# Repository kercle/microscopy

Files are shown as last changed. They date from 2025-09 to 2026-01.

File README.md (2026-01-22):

# Microscope automation project

This is a small passion project of mine in which I implement a few automations to my Bresser Researcher Trino 40-1000x. A few design-goals are:

- Minimally intrusive in the sense that the changes to the microscope should be revertible as much as possible.
- The microscope should still be fully usable in the original (analogue) way.

## Gallery

A few composite images obtained by focus stacking:

| Daphnia | Spider mite | Unknown mite |
|---|---|---|
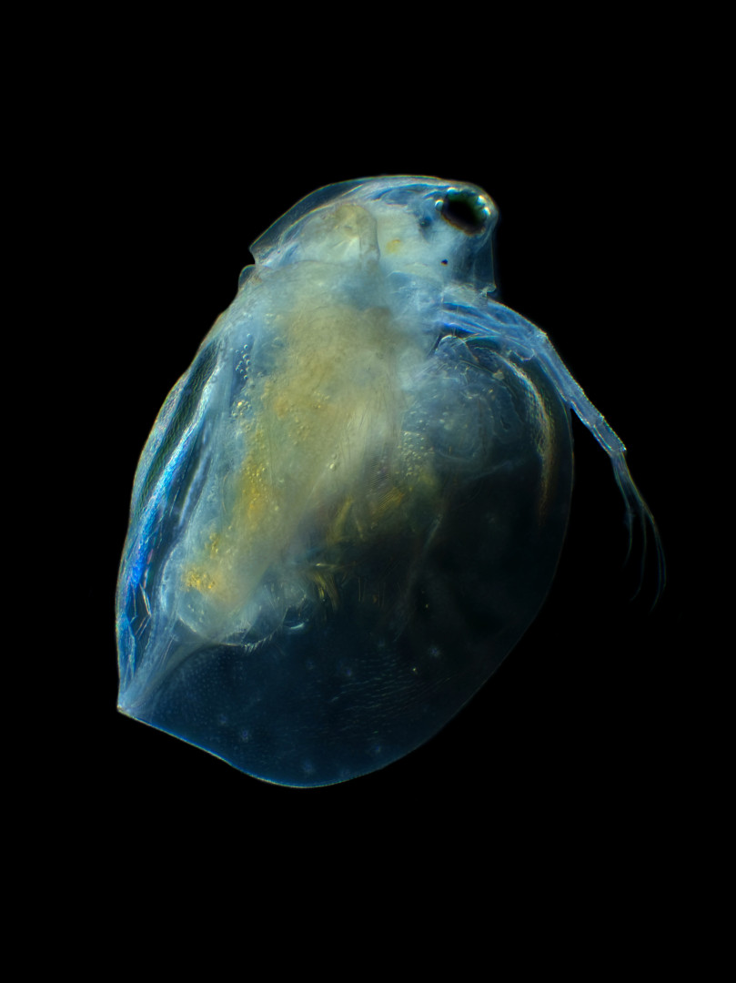
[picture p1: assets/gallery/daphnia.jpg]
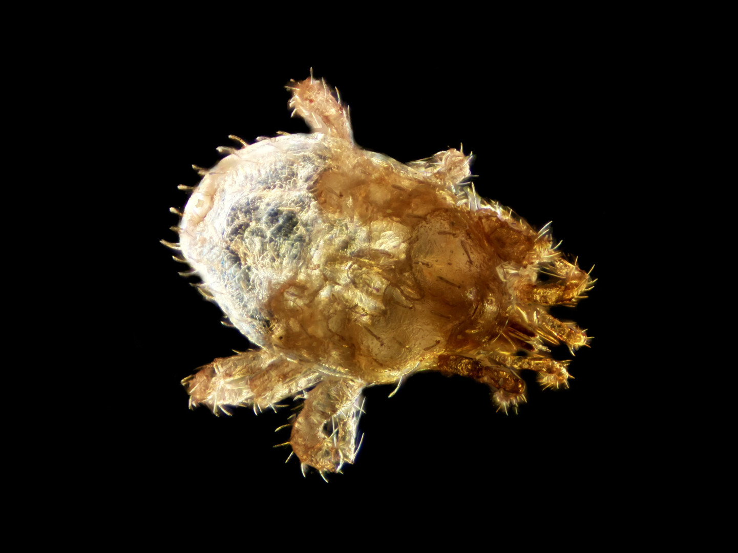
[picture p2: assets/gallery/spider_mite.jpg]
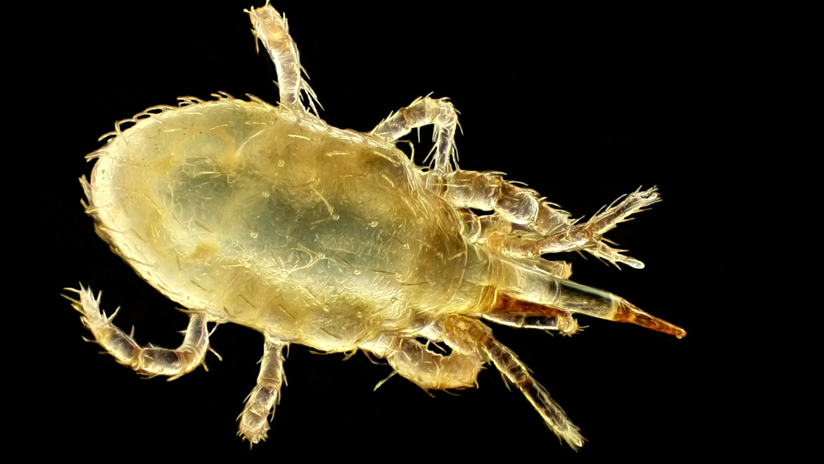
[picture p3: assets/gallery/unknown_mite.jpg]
|  |  |  |
| *Notes:* The sample was treated with bleach in order to immobilize organisms. Brownian motion was prevented by stabilizing the sample in Xanthan gum. | *Notes:* The sample was frozen to immobilize the specimen. It was taken from one of my house plants. | *Notes:* The sample was collected from the soil in one of my house plants. It was immobilized by freezing. Possibly of the order Mesostigmata. |

## Hardware

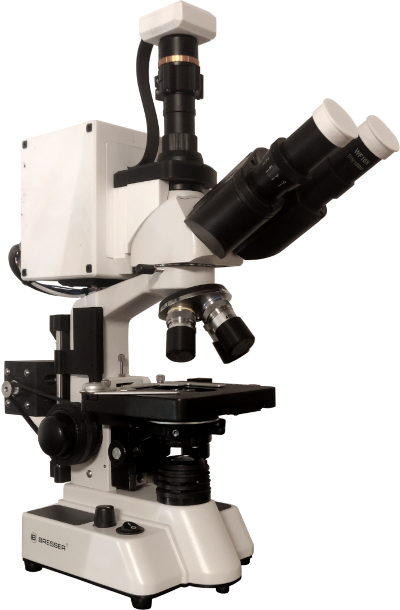
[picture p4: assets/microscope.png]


### Electronics

The control electronics is split between two controllers. The low-level control is handled by an ESP32 microcontroller, with the stepping motors being driven by TMC2208 stepper drivers.

The high-level control is handled by a Raspberry Pi 4, however the housing also allows for the installation of a Jetson Nano device instead of the Raspberry Pi.

The Raspberry Pi and ESP32 communicate over a serial connection (UART) using a custom protocol.

## Software

### User interface and backend

The user interface is a web application served by the Raspberry Pi. The frontend is built using Svelte, Tailwind CSS and DaisyUI. The backend is a Rust application using the Axum framework.

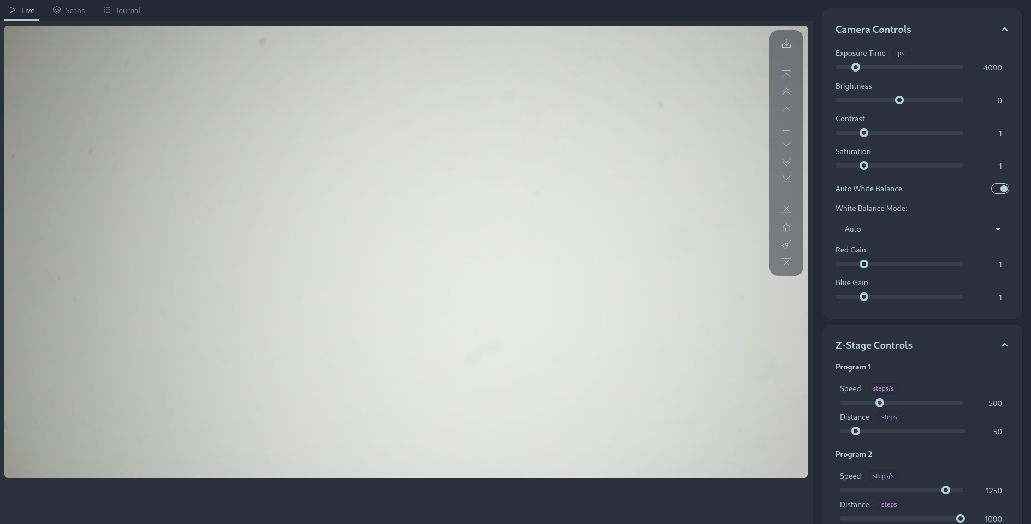
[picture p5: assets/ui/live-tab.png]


### Firmware

The ESP32 firmware is written in Rust using the `esp-idf` framework and embassy.

## Roadmap / Ideas for future work

- [x] Motorized z-axis with endstops for focusing
- [x] Web interface for controlling the microscope
- [x] Live view from camera with controls for exposure, gain, white balance, etc.
- [x] Z-stack acquisition
- [ ] Build custom focus knob which interacts with the microcontroller to allow for manual focusing when not using the web interface.
- [ ] Motorized stage for x/y movement
- [ ] Build custom stage knobs which interact with the microcontroller to allow for manual x/y
- [ ] Objective turret slot detection
- [ ] Substage illumination control
- [ ] Incident illumination

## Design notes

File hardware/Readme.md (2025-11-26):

# Hardware specifications

## Mechanical components

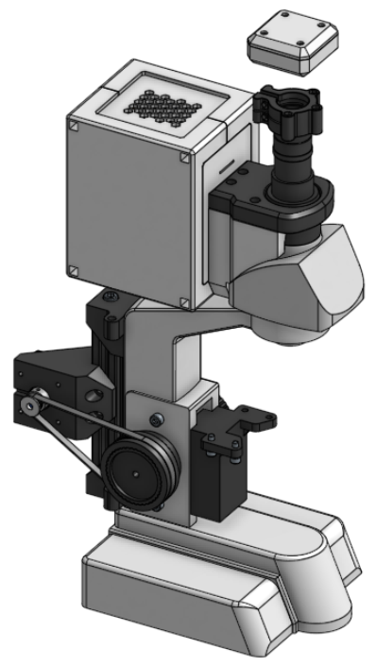
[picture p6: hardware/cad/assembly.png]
Mechanical Components


Most of the parts are 3D printed, however a few are laser cut from acrylic sheet.
Eventually, I plan to either make all of them 3D-printable and if acrylic sheets
are needed, they should be designed such that they can be cut out by hand as well
(e.g. the side panels for the electronics enclosure).

### BOM

| Part | Description | Quantity |
|---|---|---|
| | | |
| | | |

## Driver board

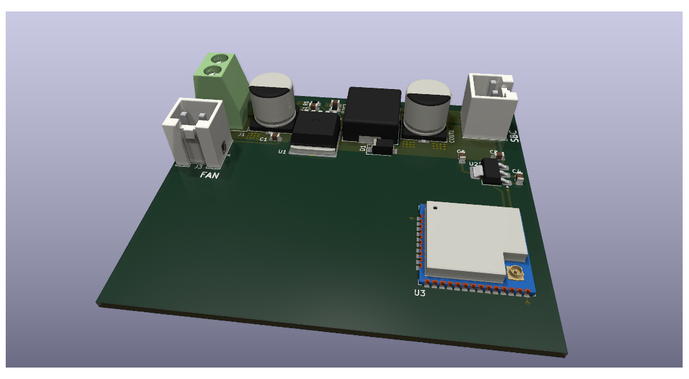
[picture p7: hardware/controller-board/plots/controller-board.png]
Driver Board


The driver board is not yet finished and so far only the power supply part is
designed, however it still needs some review, since I'm not an expert in PCB
design. The micro-controller is an ESP32-WROOM module, since the firmware is
written in Rust and the Espressif toolchain for Rust is quite mature.

### BOM

| Part | Description | Quantity |
|---|---|---|
| | | |
| | | |

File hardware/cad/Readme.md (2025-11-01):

# CAD Models

Most CAD models for this project are made in Onshape, however at some point, I would like to migrate to OpenSCAD for better version control and project portability.

The Onshape project can be found [here](https://cad.onshape.com/documents/6a7b17c2abfc874842839c22/w/c10742419820c2ced297c4e5/e/144f9c4804ce72fdaecba7c3).



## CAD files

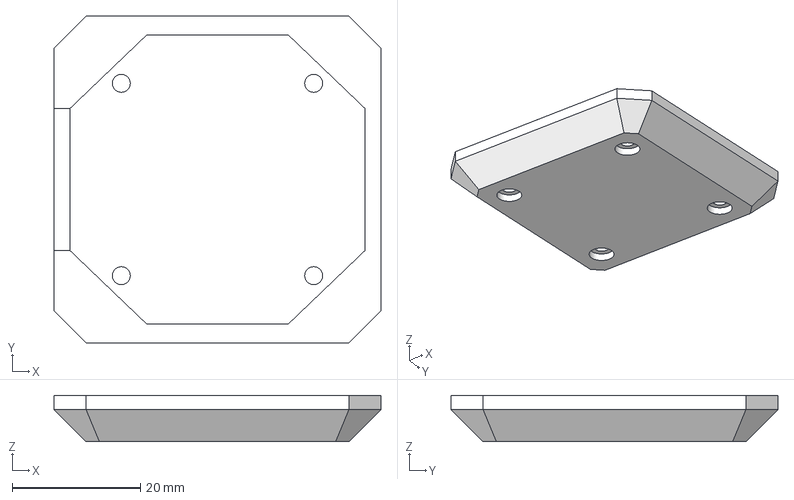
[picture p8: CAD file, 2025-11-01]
hardware/cad/camera/Camera Case - Cover.step
51.0 x 51.0 x 7.20 mm

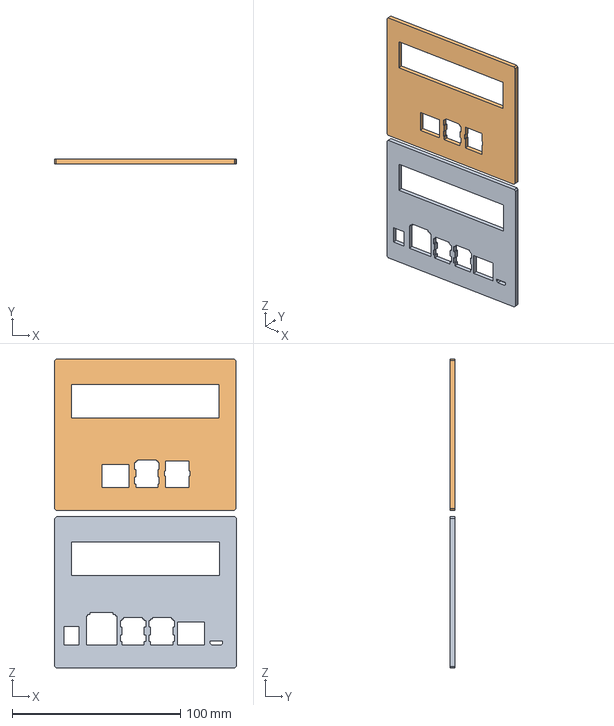
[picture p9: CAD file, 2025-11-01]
hardware/cad/housing/Port Plates.step
108.2 x 3.00 x 183.4 mm

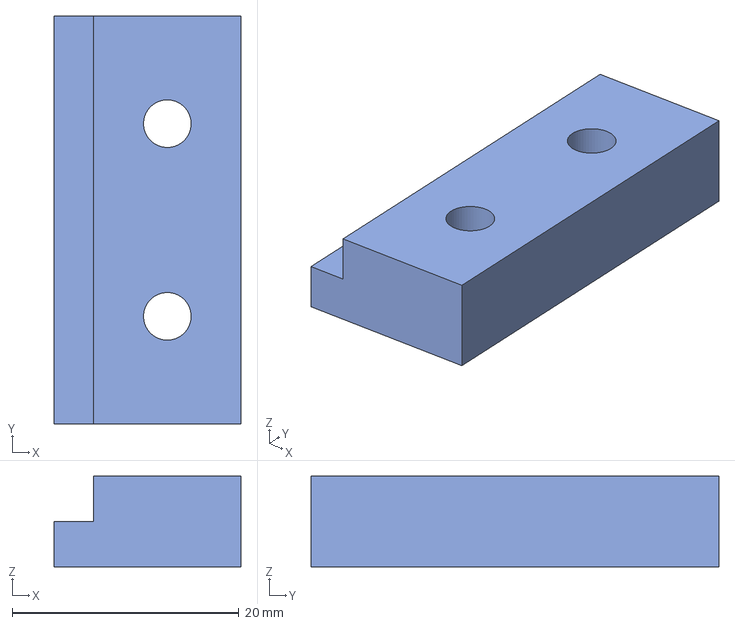
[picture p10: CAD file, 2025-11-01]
hardware/cad/mounting/Head Attachment - Retainer.step
16.5 x 36.0 x 8.00 mm

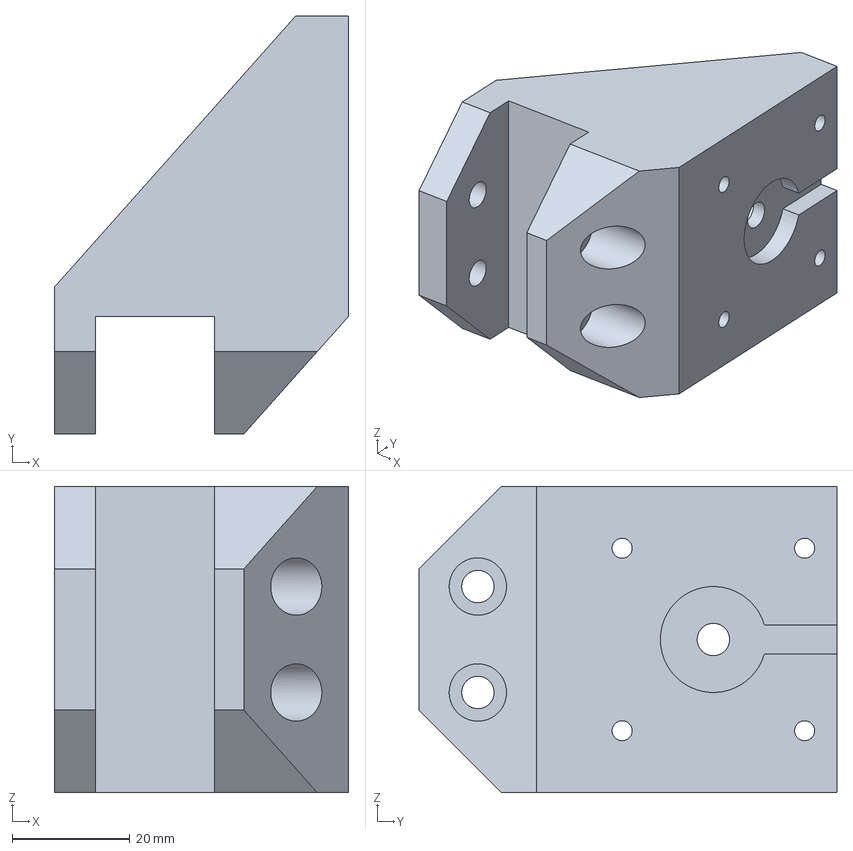
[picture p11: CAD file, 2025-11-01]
hardware/cad/z-stage/drive/Stepper - Mounting Bracket.step
50.0 x 71.0 x 52.0 mm

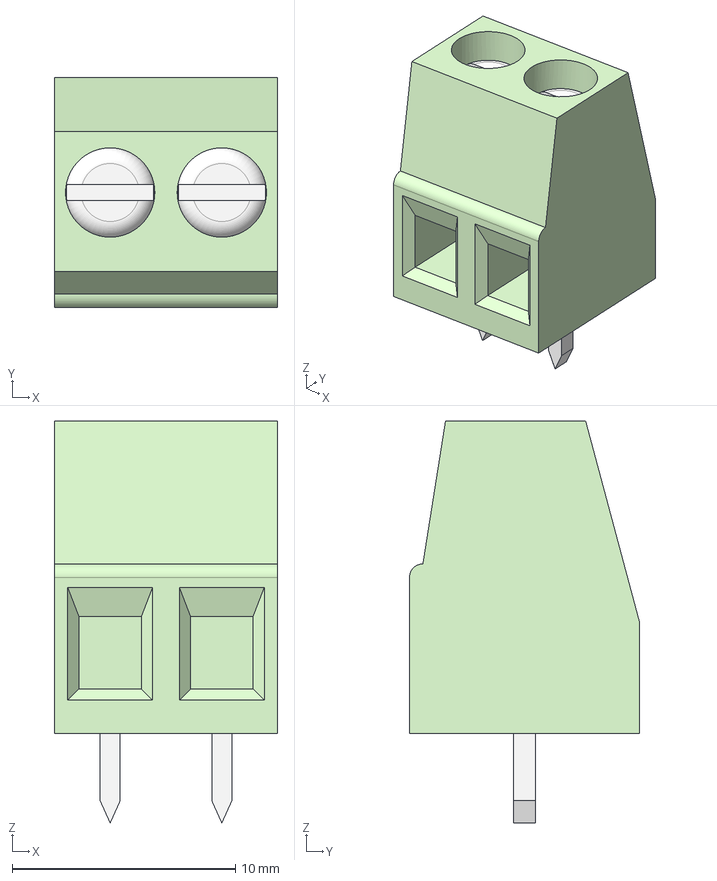
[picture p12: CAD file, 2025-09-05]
hardware/controller-board/parts/models/WJ128-5.0-2P.step
10.0 x 10.3 x 18.0 mm

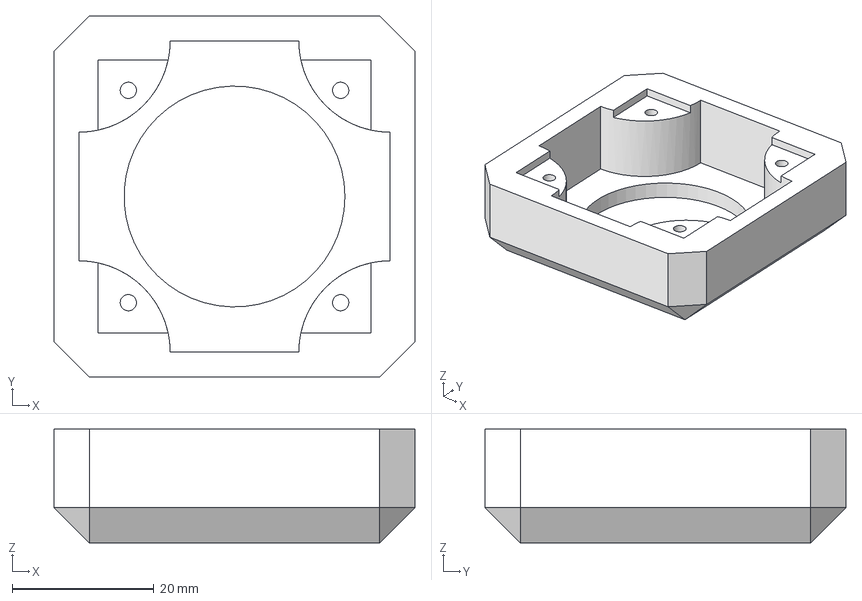
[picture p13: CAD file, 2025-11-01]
hardware/cad/camera/Camera Case - Base.step
51.0 x 51.0 x 16.1 mm

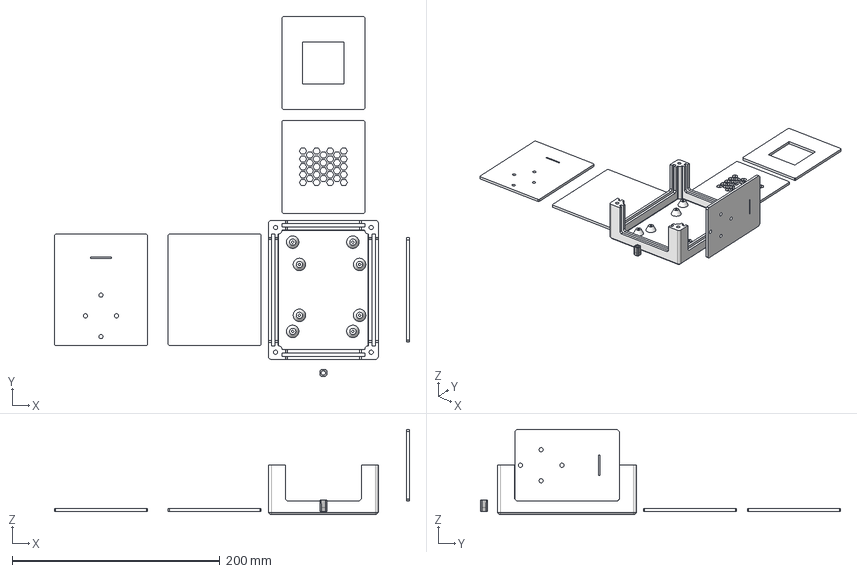
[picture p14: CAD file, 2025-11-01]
hardware/cad/housing/Electronics Housing Shell.step
342.1 x 346.9 x 82.2 mm

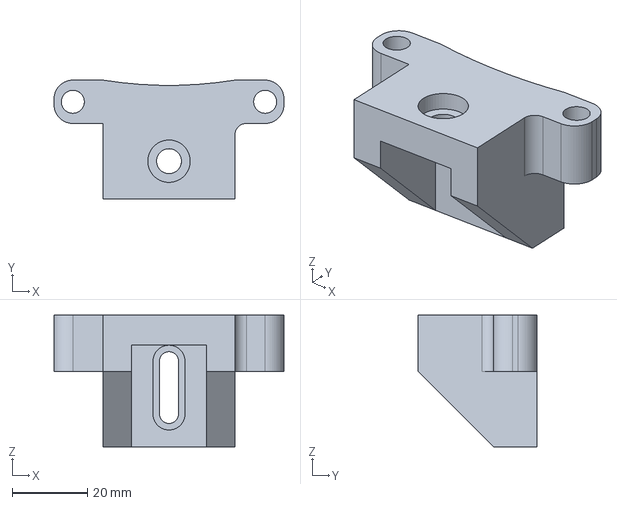
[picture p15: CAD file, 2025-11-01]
hardware/cad/mounting/Back Rail - Body Adapter.step
61.0 x 31.5 x 35.0 mm

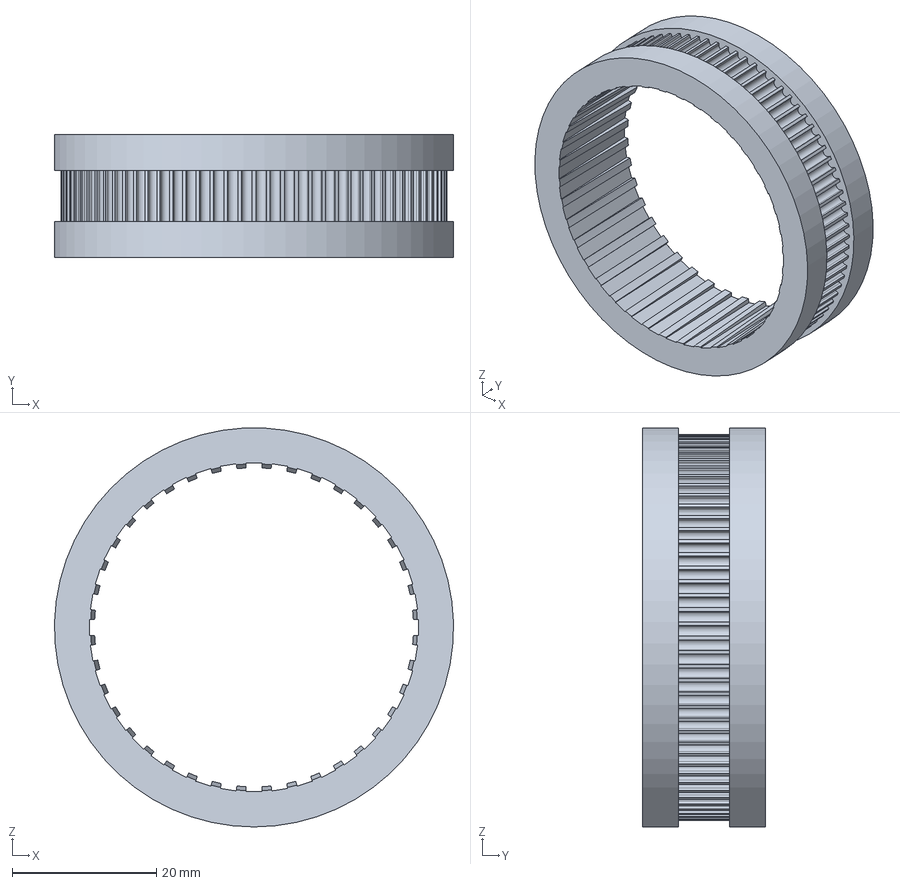
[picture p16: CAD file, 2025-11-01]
hardware/cad/z-stage/drive/Belt Focus Drive - Belt Focus Drive.step
55.3 x 17.0 x 55.3 mm

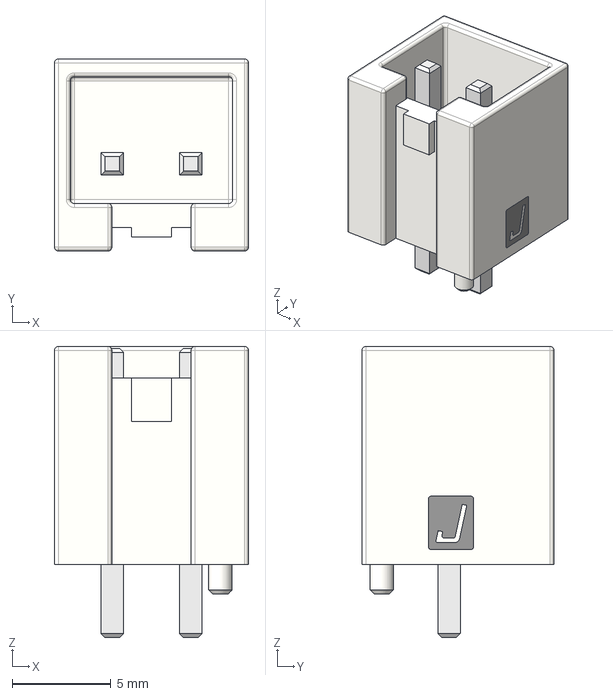
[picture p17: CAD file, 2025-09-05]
hardware/controller-board/parts/models/B2P-VH-FB-B_LF__SN_.stp
9.80 x 9.70 x 14.7 mm

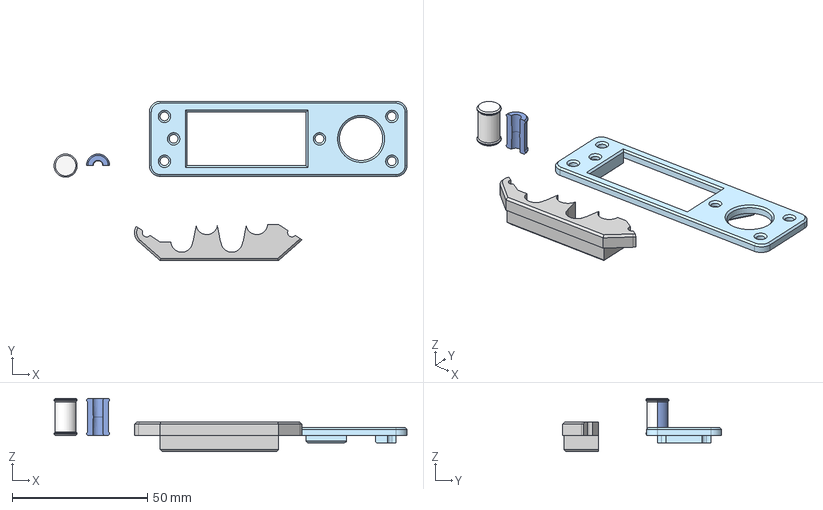
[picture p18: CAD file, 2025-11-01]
hardware/cad/housing/Custom Ports Panel.step
130.7 x 59.0 x 19.8 mm

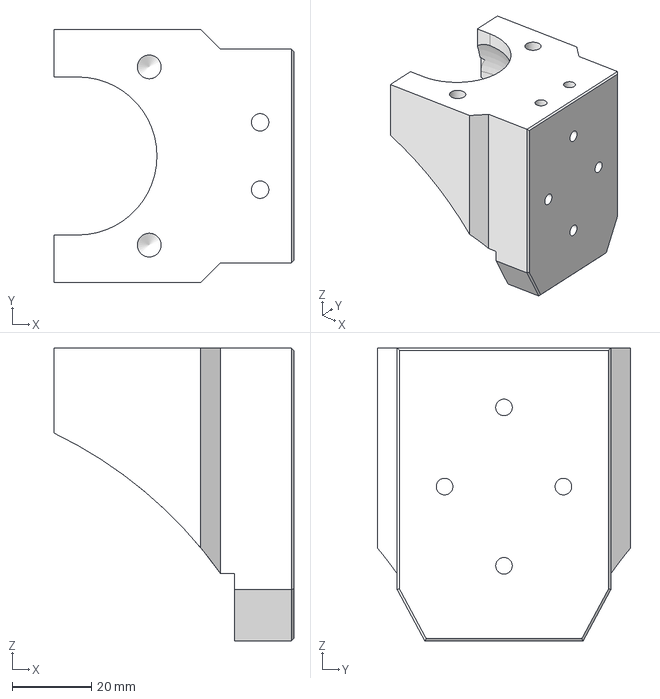
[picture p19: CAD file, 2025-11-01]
hardware/cad/mounting/Head Attachment - Head Attachment.step
60.5 x 64.0 x 74.0 mm

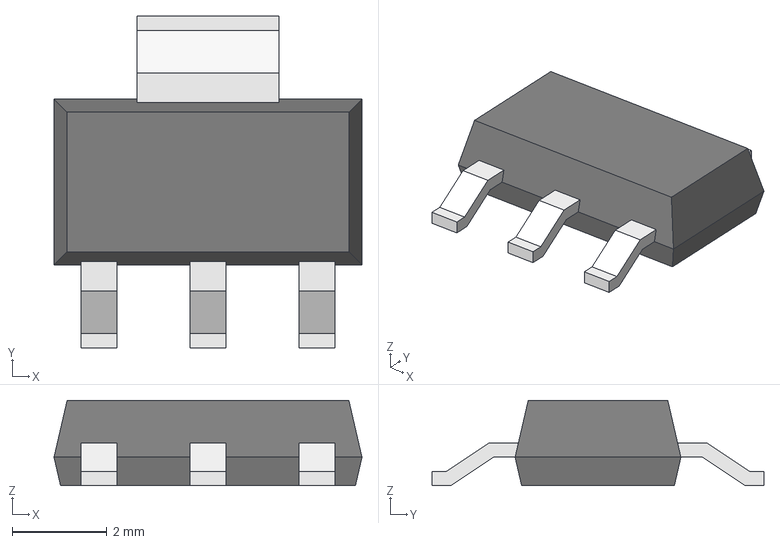
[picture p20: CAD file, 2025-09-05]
hardware/controller-board/parts/models/AMS1117.step
6.50 x 7.00 x 1.80 mm

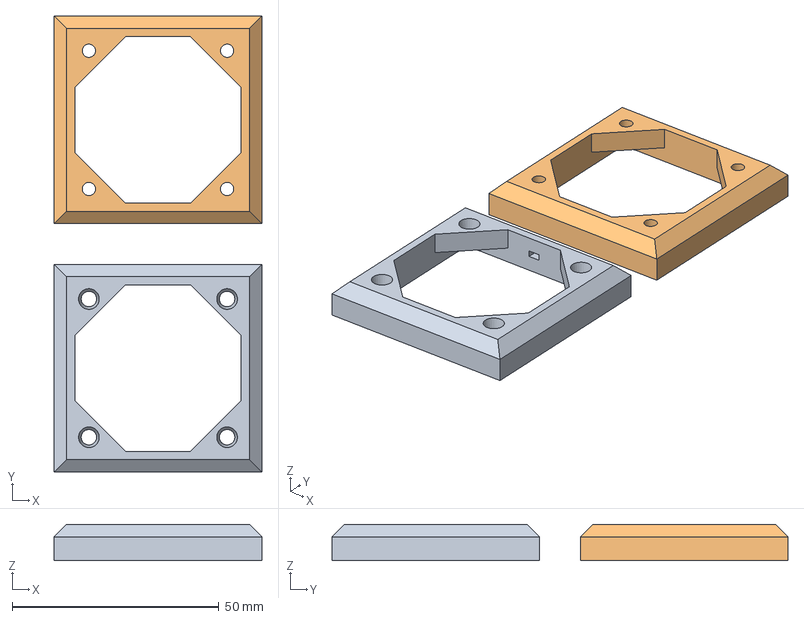
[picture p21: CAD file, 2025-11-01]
hardware/cad/housing/Fan Bracket.step
50.2 x 110.2 x 8.75 mm

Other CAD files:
hardware/cad/mounting/Reducer Lense - Clamp.step
hardware/controller-board/parts/models/YSPI1365.step
hardware/cad/mounting/Head Attachment - Bracket Top.step

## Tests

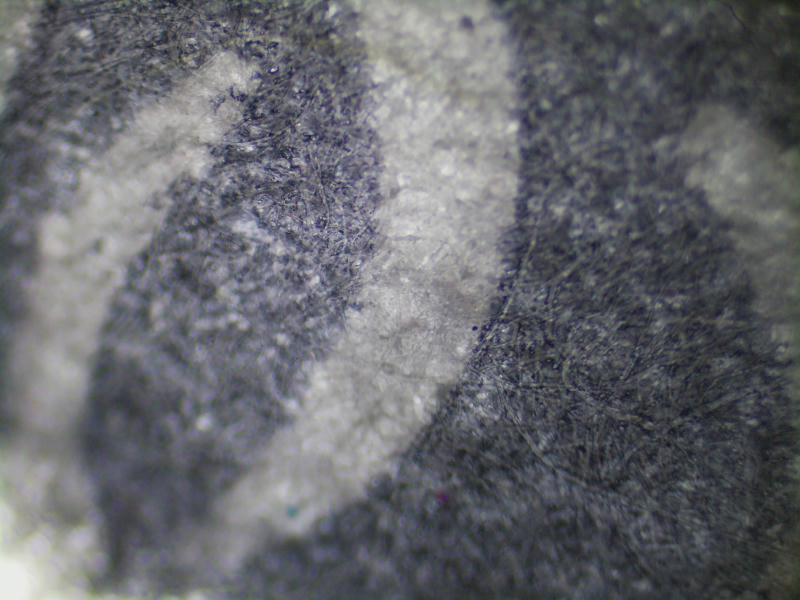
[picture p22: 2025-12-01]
software/compute-node/tests/test_image.jpg

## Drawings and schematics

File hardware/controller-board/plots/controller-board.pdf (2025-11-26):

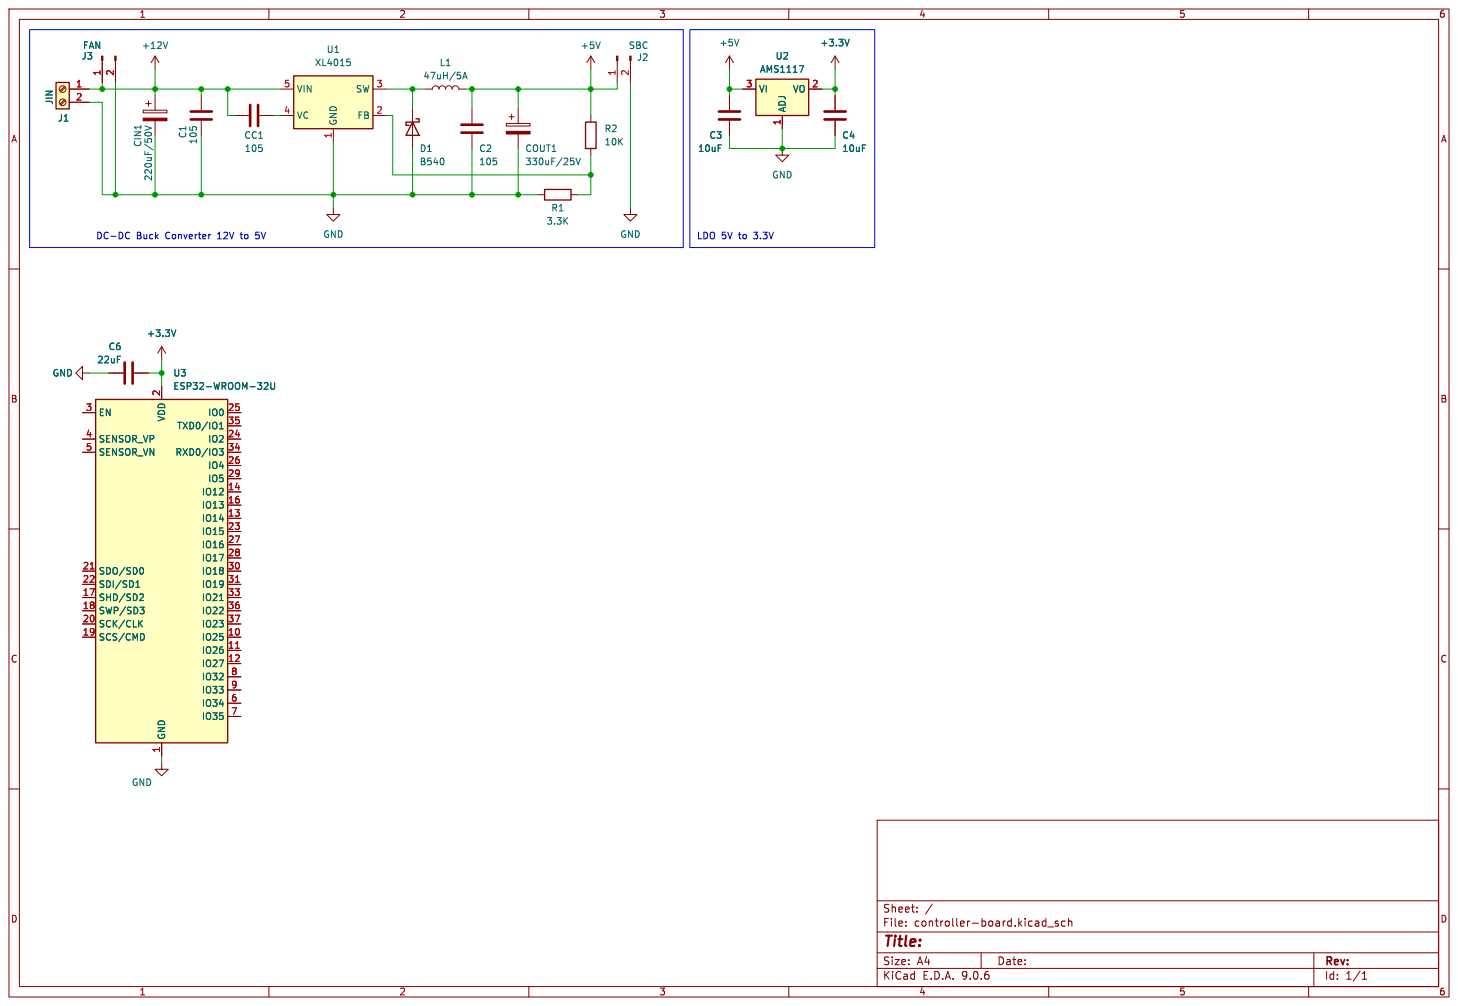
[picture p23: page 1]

Id: 1/1 Title: File: controller-board.kicad_sch Sheet: /

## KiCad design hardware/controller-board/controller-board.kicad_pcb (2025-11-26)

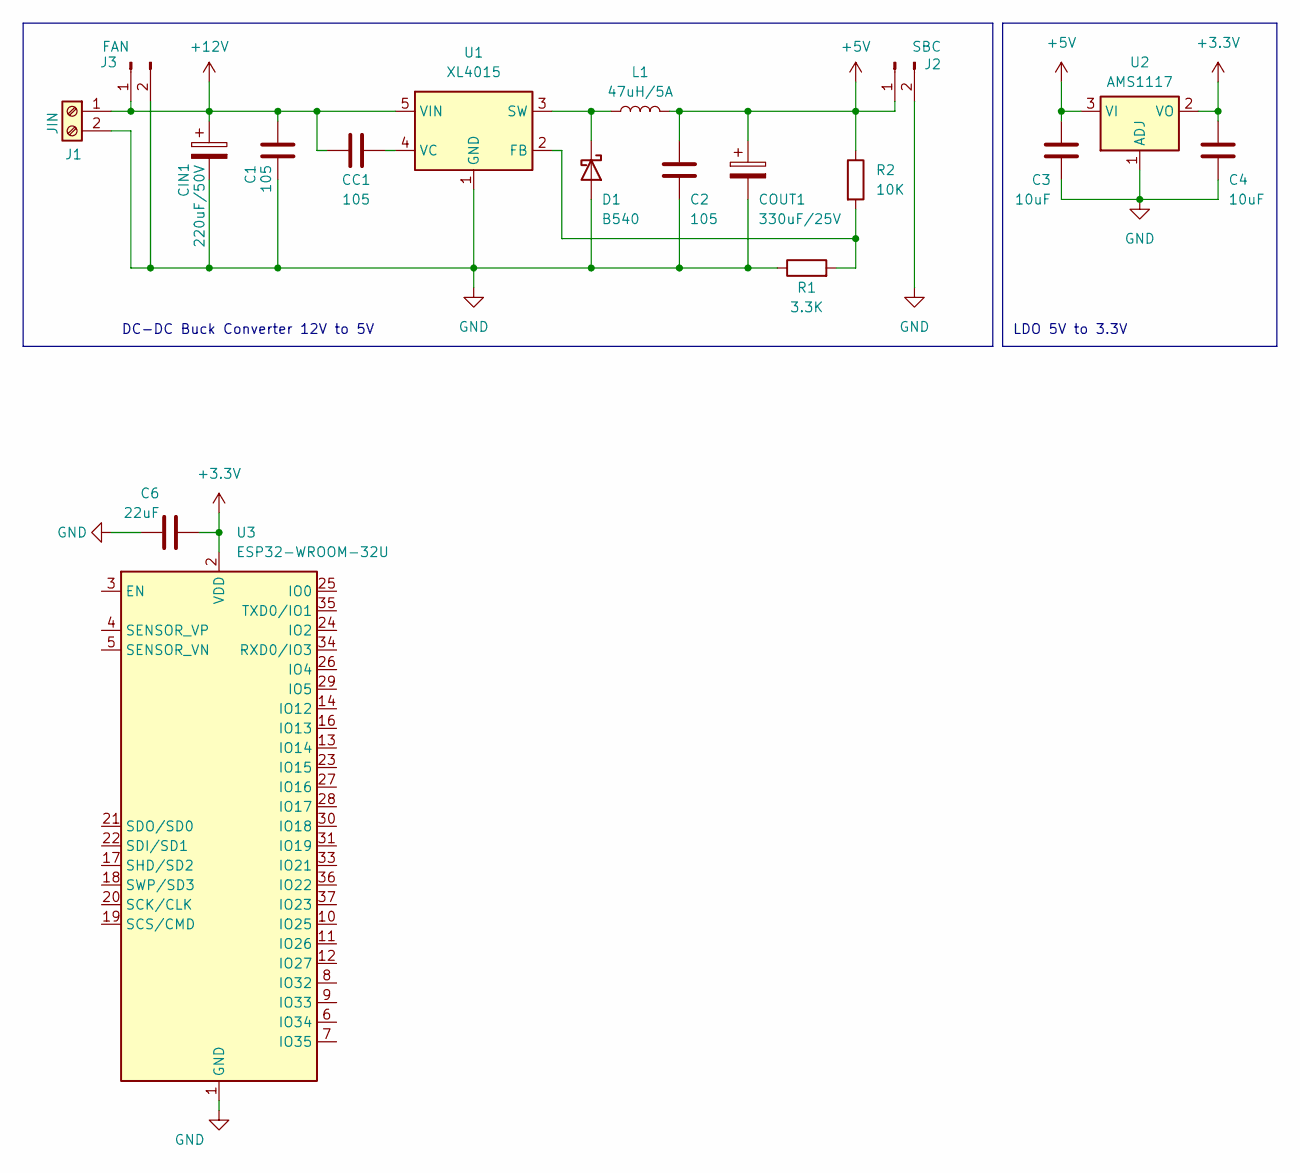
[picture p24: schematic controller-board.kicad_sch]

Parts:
C1, C2: 105; C_0805_2012Metric
C3, C4: 10uF; C_0805_2012Metric
C6: 22uF; C_0805_2012Metric
CC1: 105; C_0805_2012Metric
CIN1: 220uF/50V; CP_Elec_10x10; MFR# RVT1H221M1010 220UF 50V
COUT1: 330uF/25V; CP_Elec_10x10; MFR# RVT1H221M1010 220UF 50V
D1: B540; D_SMA
J1: JIN; TerminalBlock_Altech_AK300-2_P5.00mm
J2: SBC; JST_VH_B2P-VH-FB-B_1x02_P3.96mm_Vertical
J3: FAN; JST_VH_B2P-VH-FB-B_1x02_P3.96mm_Vertical
L1: 47uH/5A; L_Chilisin_BMRF00131360; MFR# YSPI1365-470M; JLCPCB# C497913
R1: 3.3K; R_0805_2012Metric
R2: 10K; R_0805_2012Metric
U1: XL4015; TO-263-5_TabPin3
U2: AMS1117; SOT-223-3_TabPin2
U3: ESP32-WROOM-32U

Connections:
+3.3V: C4.1, C6.2, U2.2 (VO), U3.2 (VDD)
+5V: C2.1, C3.1, COUT1.1, J2.1, L1.2, R2.1, U2.3 (VI)
+12V: C1.1, CC1.1, CIN1.1, J1.1, J3.1, U1.5 (VIN)
GND: C1.2, C2.2, C3.2, C4.2, C6.1, CIN1.2, COUT1.2, D1.2 (A), J1.2, J2.2, J3.2, R1.1, U1.1 (GND), U2.1 (ADJ), U3.1 (GND), U3.15 (GND), U3.38 (GND), U3.39 (GND)
unnamed: D1.1 (K), L1.1, U1.3 (SW)
unnamed: R1.2, R2.2, U1.2 (FB)
unnamed: CC1.2, U1.4 (VC)

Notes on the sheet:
DC-DC Buck Converter 12V to 5V
LDO 5V to 3.3V

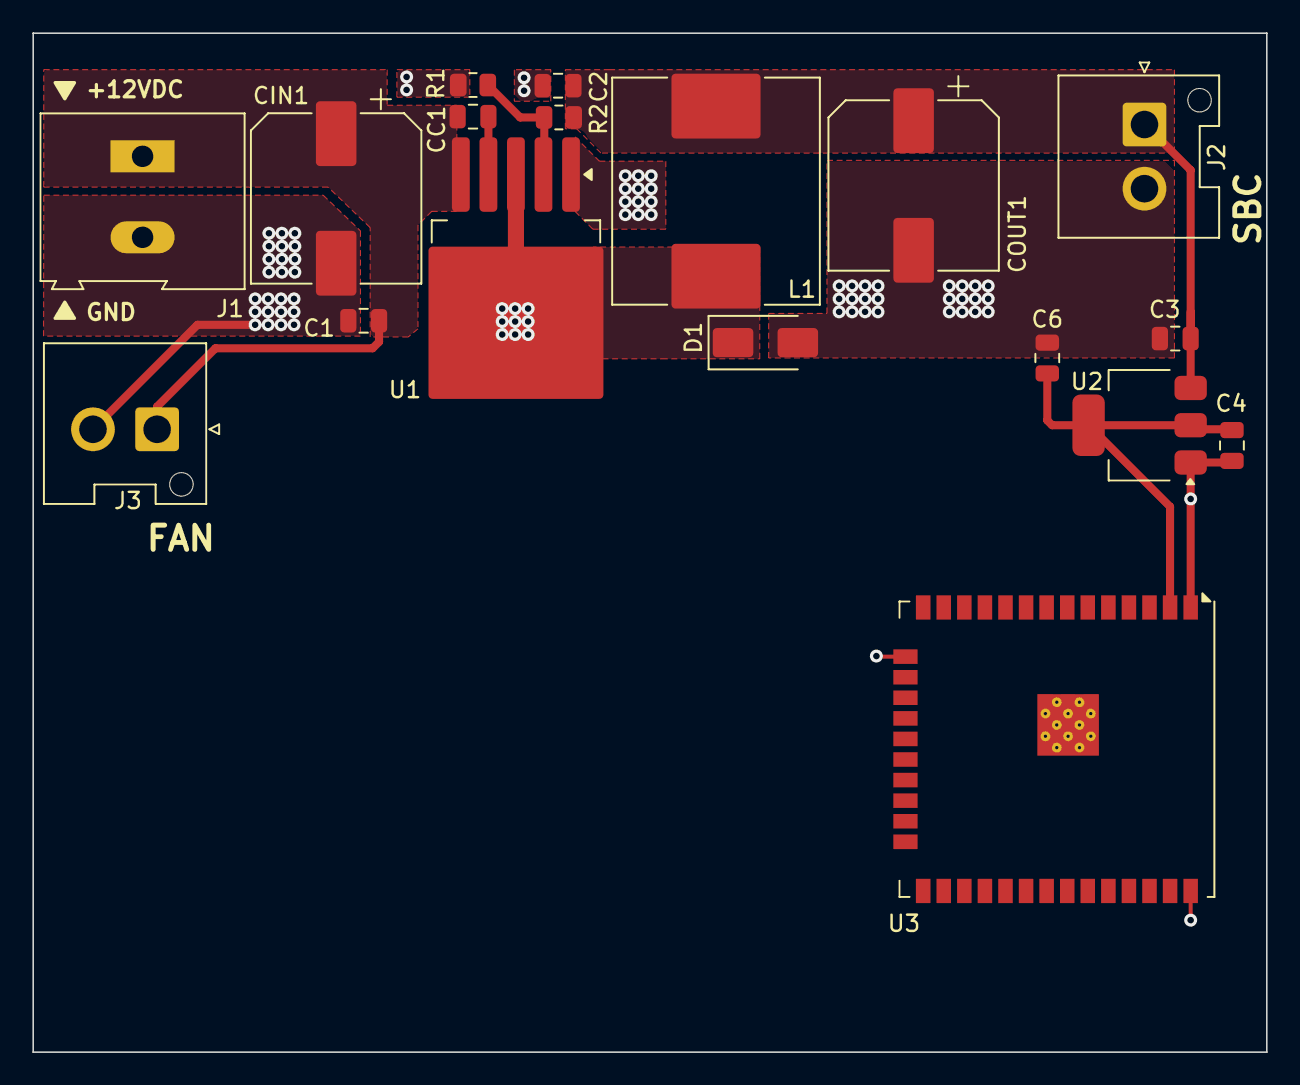
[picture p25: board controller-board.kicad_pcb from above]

Board: 2 copper layers, 76.2 x 62.9 mm, 18 parts (0 on the bottom side), 7 nets.

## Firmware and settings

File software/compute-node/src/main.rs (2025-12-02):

mod helpers;
mod tasks;
mod gpu;

use std::{collections::HashMap, env, sync::Arc};

use common::ws::{WebSocketMessage, compute_node::ComputeNodeCapabilities, value::Value};
use futures::stream::{Map, SelectAll, select_all};
use futures_util::{SinkExt, StreamExt};
use tokio::sync::mpsc;
use tokio_stream::wrappers::WatchStream;
use tokio_tungstenite::{connect_async, tungstenite::protocol::Message};
use tokio_util::sync::CancellationToken;
use tracing::{debug, error, info, warn};

use crate::gpu::GpuImageProcessor;
use crate::tasks::Task;
use crate::tasks::focus_stacking::FocusStacking;

type TaskPtr = Arc<dyn Task + Send + Sync>;

#[derive(Clone)]
struct AppState {
    cancel_token: CancellationToken,
    exec_queue_tx: mpsc::Sender<(TaskPtr, HashMap<String, Value>)>,
    tasks: HashMap<&'static str, TaskPtr>,
}

impl AppState {
    fn process_dynamic_progress(
        &self,
    ) -> SelectAll<Map<WatchStream<Option<f32>>, impl FnMut(Option<f32>) -> Option<(String, f32)>>>
    {
        let mut streams = Vec::new();

        for (task_id, task_ptr) in self.tasks.iter() {
            let receiver = task_ptr.get_progress_receiver();
            let watch_stream = WatchStream::new(receiver);
            let owned_task_id = task_id.to_string();

            let mapped_stream = watch_stream.map(move |item| {
                if let Some(progress) = item {
                    return Some((owned_task_id.clone(), progress));
                }
                None
            });

            streams.push(mapped_stream);
        }

        select_all(streams)
    }
}

async fn process_websocket_message(
    msg: WebSocketMessage,
    app_state: &AppState,
    sender_tx: &mpsc::UnboundedSender<Message>,
) {
    match msg {
        WebSocketMessage::WithTaskParams {
            task_name,
            source_uuid,
            destination_uuid: _,
            params,
            ..
        } => {
            if source_uuid.is_none() || source_uuid.is_none() {
                return;
            }

            if let Some(task) = app_state.tasks.get(task_name.as_str()) {
                let payload = serde_json::to_string(&WebSocketMessage::TaskDescription {
                    task_name: task_name.clone(),
                    source_uuid: None,
                    destination_uuid: source_uuid.unwrap(),
                    ui_description: task.describe(task_name.clone(), params).await,
                });

                if let Ok(payload) = payload {
                    let _ = sender_tx.send(Message::Text(payload.into()));
                }
            }
        }
        WebSocketMessage::StartTask {
            compute_node_uuid,
            task_name,
            params,
        } => {
            if let Some(task) = app_state.tasks.get(task_name.as_str()) {
                if let Err(e) = app_state.exec_queue_tx.try_send((task.clone(), params)) {
                    error!(
                        "Failed to enqueue FocusStacking task for compute node: {compute_node_uuid}, error: {e}"
                    );
                } else {
                    info!("Enqueued FocusStacking task for compute node: {compute_node_uuid}");
                }
            } else {
                warn!("Received StartTask for unknown task: {task_name}");
            }
        }
        _ => {
            // Ignore other message types for now
        }
    }
}

async fn process_message(
    msg: Message,
    app_state: &AppState,
    sender_tx: &mpsc::UnboundedSender<Message>,
) {
    match msg {
        Message::Text(text) => {
            debug!("Received text message: {}", text);

            if let Ok(ws_msg) = serde_json::from_str::<WebSocketMessage>(&text) {
                process_websocket_message(ws_msg, app_state, sender_tx).await;
            } else {
                warn!("Failed to parse WebSocket message");
            }
        }
        Message::Binary(bin) => {
            debug!("Received binary message: {:?}", bin);
        }
        Message::Close(frame) => {
            info!("Connection closed: {:?}", frame);
        }
        _ => {
            debug!("Received other message: {:?}", msg);
        }
    }
}

async fn processing_thread(
    app_state: AppState,
    mut exec_queue_rx: mpsc::Receiver<(TaskPtr, HashMap<String, Value>)>,
) {
    let gpu_processor = GpuImageProcessor::new().await;

    if let Err(e) = gpu_processor {
        error!("Failed to load GPU pipeline: {}", e);
        return;
    }

    let gpu_processor = gpu_processor.unwrap();

    info!("GPU pipelines initialized successfully");

    loop {
        tokio::select! {
            _ = app_state.cancel_token.cancelled() => {
                break;
            }
            Some((task, params)) = exec_queue_rx.recv() => {
                task.execute(&gpu_processor, params).await;
            }
        }
    }
}

async fn receiver_thread(
    app_state: AppState,
    sender_tx: mpsc::UnboundedSender<Message>,
    mut read: impl StreamExt<Item = Result<Message, tokio_tungstenite::tungstenite::Error>> + Unpin,
) {
    loop {
        tokio::select! {
            _ = app_state.cancel_token.cancelled() => {
                break;
            }
            msg = read.next() => {
                debug!("Received a message");
                if let Some(Ok(msg)) = msg {
                    process_message(msg, &app_state, &sender_tx).await;
                } else {
                    info!("Connection closed or error occurred");
                    break;
                }
            }
        }
    }

    app_state.cancel_token.cancel();
}

async fn sender_thread(
    app_state: AppState,
    mut sender_rx: mpsc::UnboundedReceiver<Message>,
    mut write: impl SinkExt<Message> + Unpin,
) {
    let mut progress_stream = app_state.process_dynamic_progress();

    let mut tasks = HashMap::new();
    for (task_name, task_ptr) in app_state.tasks.iter() {
        let ui_description = task_ptr
            .describe(task_name.to_string(), HashMap::new())
            .await;
        tasks.insert(task_name.to_string(), ui_description);
    }

    let capabilities = ComputeNodeCapabilities { tasks };

    let payload = serde_json::to_string(&common::ws::WebSocketMessage::RegisterComputeNode(
        capabilities,
    ))
    .unwrap();
    let _ = write.send(Message::Text(payload.into())).await;

    loop {
        tokio::select! {
            _ = app_state.cancel_token.cancelled() => {
                break;
            }
            Some(msg) = sender_rx.recv() => {
                let _ = write.send(msg).await;
            }
            Some(msg) = progress_stream.next() => {
                if msg.is_none() {
                    continue;
                }

                let (task_name, progress) = msg.unwrap();
                let payload = serde_json::to_string(&common::ws::WebSocketMessage::TaskProgressUpdate {
                    compute_node_uuid: None,
                    task_name,
                    progress,
                }).unwrap();
                let _ = write.send(Message::Text(payload.into())).await;
            }
        }
    }

    let _ = write.close().await;
}

async fn ctrlc_handler(app_state: AppState) {
    tokio::select! {
        _ = app_state.cancel_token.cancelled() => {
        }
        _ = tokio::signal::ctrl_c() => {
            info!("Ctrl-C received, shutting down...");
            app_state.cancel_token.cancel();
        }
    }
}

#[tokio::main]
async fn main() {
    let subscriber = tracing_subscriber::FmtSubscriber::new();
    tracing::subscriber::set_global_default(subscriber).expect("Setting default subscriber failed");

    let host_name = env::args()
        .nth(1)
        .unwrap_or_else(|| panic!("this program requires at least one argument"));

    let (ws_stream, _) = connect_async(format!("ws://{host_name}/api/ws"))
        .await
        .expect("Failed to connect");
    info!("WebSocket handshake has been successfully completed");

    // let task_focus_stacking: TaskPtr =
    //     ;

    let (exec_queue_tx, exec_queue_rx) = mpsc::channel::<(TaskPtr, HashMap<String, Value>)>(100);
    let app_state = AppState {
        cancel_token: CancellationToken::new(),
        exec_queue_tx,
        tasks: HashMap::from([(
            "focus_stacking",
            Arc::new(FocusStacking::new(host_name.clone())) as TaskPtr,
        )]),
    };

    let (sender_tx, sender_rx) = mpsc::unbounded_channel();
    let (write, read) = ws_stream.split();

    tokio::spawn(ctrlc_handler(app_state.clone()));
    tokio::select! {
        _ = processing_thread(app_state.clone(), exec_queue_rx) => {
        }
        _ = receiver_thread(app_state.clone(), sender_tx, read) => {
        }
        _ = sender_thread(app_state.clone(), sender_rx, write) => {
        }
    }
}

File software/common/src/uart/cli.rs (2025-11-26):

use std::{str::FromStr, time::Duration};

use common::uart::{HostCommand, driver::DeviceDriver};
use tokio::sync::mpsc;
use tokio_util::sync::CancellationToken;

use anyhow::Result;
use ratatui::{
    DefaultTerminal, Frame,
    crossterm::event::{self, Event, KeyCode, KeyEventKind},
    layout::{Constraint, Layout, Position},
    style::{Color, Modifier, Style, Stylize},
    text::{Line, Text},
    widgets::{Block, List, ListItem, Paragraph},
};

type DeviceEvent = common::uart::DeviceEvent<String>;

#[tokio::main]
async fn main() -> Result<()> {
    let terminal = ratatui::init();
    let app_result = App::new().run(terminal).await;
    ratatui::restore();
    app_result
}

enum Message {
    HostCommand(HostCommand),
    DeviceEvent(DeviceEvent),
    HostLog {
        level: common::uart::LogMessageLevel,
        message: String,
    },
}

struct App {
    history_cursor: usize,
    input_history: Vec<String>,
    input: String,
    character_index: usize,
    input_mode: InputMode,
    messages: Vec<Message>,
}

#[derive(Debug, Clone)]
enum InputMode {
    Monitor,
    Command,
}

enum AppEvent {
    Exit,
    SetInputMode(InputMode),
    SubmitCommand,
    DisplayMessage(Message),
    EnterChar(char),
    DeleteChar,
    MoveCursorLeft,
    MoveCursorRight,
    ScrollUpHistory,
    ScrollDownHistory,
}

impl App {
    fn new() -> Self {
        Self {
            history_cursor: 0,
            input_history: Vec::new(),
            input: String::new(),
            input_mode: InputMode::Monitor,
            messages: Vec::new(),
            character_index: 0,
        }
    }

    fn move_cursor_left(&mut self) {
        let cursor_moved_left = self.character_index.saturating_sub(1);
        self.character_index = self.clamp_cursor(cursor_moved_left);
    }

    fn move_cursor_right(&mut self) {
        let cursor_moved_right = self.character_index.saturating_add(1);
        self.character_index = self.clamp_cursor(cursor_moved_right);
    }

    fn enter_char(&mut self, new_char: char) {
        let index = self.byte_index();
        self.input.insert(index, new_char);
        self.move_cursor_right();
    }

    /// Returns the byte index based on the character position.
    ///
    /// Since each character in a string can be contain multiple bytes, it's necessary to calculate
    /// the byte index based on the index of the character.
    fn byte_index(&self) -> usize {
        self.input
            .char_indices()
            .map(|(i, _)| i)
            .nth(self.character_index)
            .unwrap_or(self.input.len())
    }

    fn delete_char(&mut self) {
        let is_not_cursor_leftmost = self.character_index != 0;
        if is_not_cursor_leftmost {
            // Method "remove" is not used on the saved text for deleting the selected char.
            // Reason: Using remove on String works on bytes instead of the chars.
            // Using remove would require special care because of char boundaries.

            let current_index = self.character_index;
            let from_left_to_current_index = current_index - 1;

            // Getting all characters before the selected character.
            let before_char_to_delete = self.input.chars().take(from_left_to_current_index);
            // Getting all characters after selected character.
            let after_char_to_delete = self.input.chars().skip(current_index);

            // Put all characters together except the selected one.
            // By leaving the selected one out, it is forgotten and therefore deleted.
            self.input = before_char_to_delete.chain(after_char_to_delete).collect();
            self.move_cursor_left();
        }
    }

    fn clamp_cursor(&self, new_cursor_pos: usize) -> usize {
        new_cursor_pos.clamp(0, self.input.chars().count())
    }

    fn reset_cursor(&mut self) {
        self.character_index = 0;
    }

    async fn submit_message(&mut self, message: Message) {
        self.messages.push(message);
        self.input.clear();
        self.reset_cursor();
    }

    // async fn display_device_event(
    //     app_event_tx: &mpsc::Sender<AppEvent>,
    //     event: DeviceEvent,
    // ) -> Result<()> {
    //     match event {
    //         DeviceEvent::LogMessage { level: _, message } => {
    //             app_event_tx.try_send(AppEvent::DisplayMessage(message))
    //         }
    //         _ => app_event_tx.try_send(AppEvent::DisplayMessage(
    //             "unimplemented device event.".into(),
    //         )),
    //     }
    //     .map_err(|e| anyhow::anyhow!("Failed to send device event: {e}"))
    // }

    async fn serial_port_com(
        app_event_tx: mpsc::Sender<AppEvent>,
        mut host_cmd_rx: mpsc::Receiver<HostCommand>,
        quit_notify: CancellationToken,
    ) -> Result<()> {
        // TODO: Make port configurable

        let mut driver = DeviceDriver::new(std::path::Path::new("/dev/ttyUSB0"), 115_200)?;
        driver.reset().await?;

        while !driver.connection_established::<String>() {
            if quit_notify.is_cancelled() {
                return Ok(());
            }
            tokio::time::sleep(Duration::from_millis(20)).await;
        }

        app_event_tx
            .try_send(AppEvent::DisplayMessage(Message::HostLog {
                level: common::uart::LogMessageLevel::Info,
                message: "Connection established.".into(),
            }))
            .ok();

        while !quit_notify.is_cancelled() {
            while let Ok(cmd) = host_cmd_rx.try_recv() {
                driver.send_command::<String>(cmd).await?;
            }

            if let Some(event) = driver.recv_event::<String>()? {
                app_event_tx
                    .send(AppEvent::DisplayMessage(Message::DeviceEvent(event)))
                    .await?;
            } else {
                tokio::time::sleep(Duration::from_millis(20)).await;
            }
        }

        Ok(())
    }

    async fn process_key_events(
        mut input_mode: InputMode,
        app_event_tx: mpsc::Sender<AppEvent>,
        quit_notify: CancellationToken,
    ) -> Result<()> {
        while !quit_notify.is_cancelled() {
            let event = if let Ok(event) = tokio::task::spawn_blocking(event::read).await {
                event?
            } else {
                continue;
            };
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

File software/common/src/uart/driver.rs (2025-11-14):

#[cfg(feature = "std")]
extern crate std;

use std::boxed::Box;
use std::path::Path;
use std::vec::Vec;

use anyhow::Result;
use serde::{Serialize, de::DeserializeOwned};
use serialport::SerialPort;

use crate::uart::{DeviceEvent, HostCommand};

type EventBuffer = [u8; 4096];

pub struct DeviceDriver {
    pub port: Box<dyn SerialPort>,
    pub buffer: Vec<u8>,
    pub signature_received: bool,
}

impl DeviceDriver {
    pub fn new(serial_port: &Path, baud_rate: u32) -> Result<Self> {
        Ok(DeviceDriver {
            port: serialport::new(serial_port.to_str().unwrap(), baud_rate)
                .timeout(std::time::Duration::from_millis(10))
                .open()?,
            buffer: Vec::new(),
            signature_received: false,
        })
    }

    pub async fn reset(&mut self) -> serialport::Result<()> {
        self.port.write_data_terminal_ready(false)?;

        self.port.write_request_to_send(true)?;
        tokio::time::sleep(std::time::Duration::from_millis(100)).await;
        self.port.write_request_to_send(false)?;
        tokio::time::sleep(std::time::Duration::from_millis(200)).await; // wait for device to reboot
        Ok(())
    }

    fn verify_signature<StrType: Serialize + DeserializeOwned>(&mut self) -> bool {
        let mut init_packet: EventBuffer = [0; 4096];
        let init_package_size = DeviceEvent::<StrType>::InitSignature
            .encode_bytes(&mut init_packet)
            .unwrap();

        if self.buffer.len() < init_package_size + 1 {
            return false;
        }

        for i in 0..self.buffer.len() - init_package_size + 1 {
            if self.buffer[i..].starts_with(&init_packet[..init_package_size]) {
                self.buffer.drain(..i + init_package_size + 1); // +1 to also remove the null terminator
                self.signature_received = true;
                return true;
            }
        }

        false
    }

    pub fn extend_buffer(&mut self) -> Result<usize> {
        let bytes_available = self.port.bytes_to_read()?;
        if bytes_available == 0 {
            return Ok(0);
        }

        let mut buf = std::vec![0u8; bytes_available as usize];
        let n = self
            .port
            .read(&mut buf)
            .inspect(|&n| self.buffer.extend_from_slice(&buf[..n]))?;

        Ok(n)
    }

    pub fn connection_established<StrType: Serialize + DeserializeOwned>(&mut self) -> bool {
        if self.signature_received {
            return true;
        }

        if self.extend_buffer().is_ok() {
            self.verify_signature::<StrType>()
        } else {
            false
        }
    }

    fn decode_next_event<StrType: Serialize + DeserializeOwned>(
        &mut self,
    ) -> Result<Option<DeviceEvent<StrType>>> {
        if !self.connection_established::<StrType>() {
            return Ok(None);
        }

        let res = if let Some(pos) = self.buffer.iter().position(|&x| x == 0) {
            let packet = self.buffer.drain(..=pos).collect::<Vec<u8>>();
            Some(DeviceEvent::<StrType>::decode_bytes(&packet).map_err(|e| {
                anyhow::anyhow!("Failed to decode packet: {:?}, error: {:?}", packet, e)
            })?)
        } else {
            None
        };

        Ok(res)
    }

    pub fn recv_event<StrType: Serialize + DeserializeOwned>(
        &mut self,
    ) -> Result<Option<DeviceEvent<StrType>>> {
        self.extend_buffer()?;
        self.decode_next_event()
    }

    pub async fn send_command<StrType: Serialize + DeserializeOwned>(
        &mut self,
        cmd: HostCommand,
    ) -> Result<()> {
        if !self.connection_established::<StrType>() {
            return Err(anyhow::anyhow!(
                "Connection not established. Cannot send command."
            ));
        }

        let mut buffer: EventBuffer = [0; 4096];
        let packet_size = cmd
            .encode_bytes(&mut buffer)
            .map_err(|e| anyhow::anyhow!("Failed to encode command: {:?}", e))?;
        self.port.write_all(&buffer[..packet_size])?;
        self.port.write_all(&[0u8])?; // Null-terminate
        self.port.flush()?;

        tokio::time::sleep(std::time::Duration::from_millis(20)).await;

        Ok(())
    }

    pub async fn home<StrType: Serialize + DeserializeOwned>(&mut self) -> Result<()> {
        self.send_command::<StrType>(HostCommand::StageMotor(crate::uart::StageMotorCmd::Home))
            .await
    }

    pub async fn set_upper_limit<StrType: Serialize + DeserializeOwned>(
        &mut self,
        position: i32,
    ) -> Result<()> {
        self.send_command::<StrType>(HostCommand::StageMotor(
            crate::uart::StageMotorCmd::SetUpperLimit(position),
        ))
        .await
    }

    pub async fn stage_move_steps<StrType: Serialize + DeserializeOwned>(
        &mut self,
        steps: i32,
        step_delay_us: u32,
    ) -> Result<()> {
        self.send_command::<StrType>(HostCommand::StageMotor(
            crate::uart::StageMotorCmd::MoveSteps {
                steps,
                step_delay_us,
            },
        ))
        .await
    }
}

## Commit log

2025-09-05 Starting designing the controller board.
    [AMS1117.step, B2P-VH-FB-B_LF__SN_.stp, WJ128-5.0-2P.step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]
2025-09-05 Ignore Kicad backups.
2025-09-08 Connect MJPEG stream to gstreamer camera.
2025-09-08 Increase frame size a bit.
2025-09-08 Work on web-socket interaction between frontend and backend.
2025-09-18 Add a button to download hi-res photos.
2025-09-20 Toggle of GPIO2 and printing 'Hello World!' from Esp32.
2025-09-21 Testing stage z-axis motor.
2025-09-21 Move controller board into hardware section.
    [AMS1117.step, B2P-VH-FB-B_LF__SN_.stp, WJ128-5.0-2P.step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]
2025-09-21 Add recipe for flashing esp32.
2025-09-21 Remove prints from firmware and link against com lib.
2025-09-21 Simplify firmware file hierarchy and fix rust warnings.
    [main.rs]
2025-09-21 WIP: Uart communication.
2025-09-21 Set up UART to communicate with SBC.
2025-09-22 Decode an print device events.
2025-09-22 Implement a driver for the serial port for easy integration.
2025-09-22 Cleaner error handling in CLI tool.
    [cli.rs]
2025-09-22 Add function for resetting the device.
    [driver.rs]
2025-09-23 Fancier printing of events.
2025-09-23 Add stage motor stop command.
2025-09-23 Implement stage motor stop command in firmware.
2025-09-23 Adding more commands for the stage motor.
2025-09-23 Create dedicated module for stage motor in firmware code and add more commands.
2025-09-23 Let the backend connect to the controller board via the serial port.
2025-09-23 Add REST endpoints for motor controller.
2025-09-26 Add more buttons for controlling the zStage from the frontend.
2025-09-26 Implement homing mechanic in firmware.
2025-09-26 Add homing feature to backend and frontend.
2025-10-03 Use heapless's own format instead of assembling log message using push_str and automatically home when firmware starts.
2025-10-03 Rely on the firmware to run th homing on controller startup.
2025-10-03 Rearrange match statement in motor_task.
2025-10-28 Add a semaphore to AppState in order to guard certain actions which are mutually exclusive, like taking photos and scanning a sample.
2025-10-28 Add a function to move the stage.
2025-10-29 Allow for bi-directional z-scans and configurable directory for storing z-scan frames together with metadata.
2025-10-30 Draft sample scan control page.
2025-10-30 Refine sample scan control page.
2025-10-31 Connect sample scan page frontend to backend.
2025-11-01 In the Z-Scan thumbnails, use the middle frame in the list.
2025-11-01 Added a bit of documentation and CAD models.
    [Back Rail - Body Adapter.step, Belt Focus Drive - Belt Focus Drive.step, Camera Case - Base.step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]
2025-11-02 Add endpoint for downloading full-size frames from z-scans.
2025-11-02 Move CAD data into hardware folder.
    [Back Rail - Body Adapter.step, Belt Focus Drive - Belt Focus Drive.step, Camera Case - Base.step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]
2025-11-14 Move the UART specific communication protocol into its own submodule to have a shares WS communication module for the compute nodes and the microscope.
2025-11-14 Populate first datastructures for centralizing web-socket protocol specification.
2025-11-14 Refactor CameraProperties and Parameters.
    The two structs are moved to the communication crate in order to unify the interface between the different components.
2025-11-14 Fix ttyUSB naming ambiguity by adding udev rules and refering to the respective unique ID.
    [serve.rs]
2025-11-14 Add dedicated function to process text payloads received via web socket.
2025-11-14 Parse web socket text payload in process_message function and pass result on to process_parsed_message.
2025-11-18 Track procedure ID and compute node ID in frontend for compute nodes.
2025-11-26 Added a bit of documentation for the hardware side-of-things.
    [controller-board.kicad_pcb]
2025-11-29 Fix minor issues from renaming procedures to tasks and print mock process to test signal chain.
    [mod.rs]
2025-11-29 Relay progress of compute tasks to sender thread in compute nodes.
2025-11-30 Download frames from z-stack in focus stacking task.
2025-12-01 Implement a test for the sobel filter.
2025-12-01 Finalize initial implementation of `GpuImageProcessor` with sobel filter.
2025-12-02 Apply sobel filter to recorded image stack in focus stacking.
2025-12-02 Remove Gaussian blur filter again.
2025-12-02 Implement more convenient way of chaining filters.
2025-12-02 Assemble final image in focus stacking.
